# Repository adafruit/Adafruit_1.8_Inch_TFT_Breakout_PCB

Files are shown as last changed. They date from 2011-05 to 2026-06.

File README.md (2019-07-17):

# 1.8" Color TFT LCD display with MicroSD Card Breakout

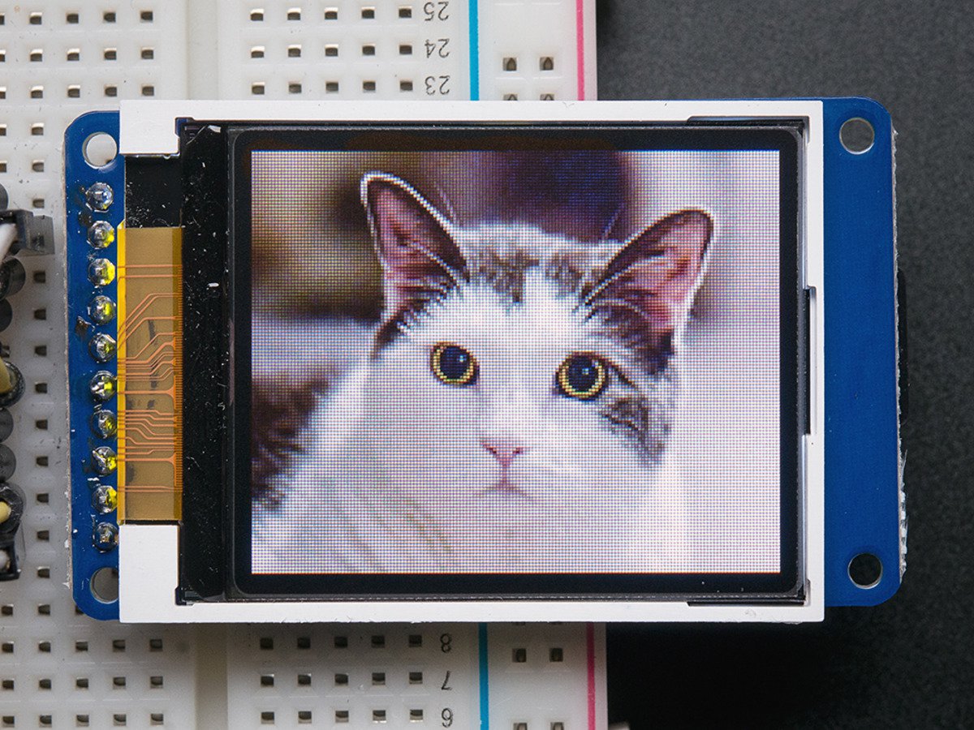
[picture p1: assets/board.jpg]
<a href="http://www.adafruit.com/products/358"><br/>Click here to purchase one from the Adafruit shop</a>

This lovely little display breakout is the best way to add a small, colorful and bright display to any project. Since the display uses 4-wire SPI to communicate and has its own pixel-addressable frame buffer, it can be used with every kind of microcontroller. Even a very small one with low memory and few pins available!

The 1.8" display has 128x160 color pixels. Unlike the low cost "Nokia 6110" and similar LCD displays, which are CSTN type and thus have poor color and slow refresh, this display is a true TFT! The TFT driver (ST7735R) can display full 18-bit color (262,144 shades!). And the LCD will always come with the same driver chip so there's no worries that your code will not work from one to the other.

The breakout has the TFT display soldered on (it uses a delicate flex-circuit connector) as well as a ultra-low-dropout 3.3V regulator and a 3/5V level shifter so you can use it with 3.3V or 5V power and logic. We also had a little space so we placed a microSD card holder so you can easily load full color bitmaps from a FAT16/FAT32 formatted microSD card. The microSD card is not included, [but you can pick one up here](https://www.adafruit.com/product/102).

Of course, we wouldn't just leave you with a datasheet and a "good luck!" - [we've written a full open source graphics library that can draw pixels, lines, rectangles, circles, text and bitmaps as well as example code and a wiring tutorial](https://learn.adafruit.com/1-8-tft-display). The code is written for Arduino but can be easily ported to your favorite microcontroller!

### License

Adafruit invests time and resources providing this open source design, please support Adafruit and open-source hardware by purchasing products from [Adafruit](https://www.adafruit.com)!

Designed by Limor Fried/Ladyada for Adafruit Industries.

Creative Commons Attribution/Share-Alike, all text above must be included in any redistribution. See license.txt for additional details.

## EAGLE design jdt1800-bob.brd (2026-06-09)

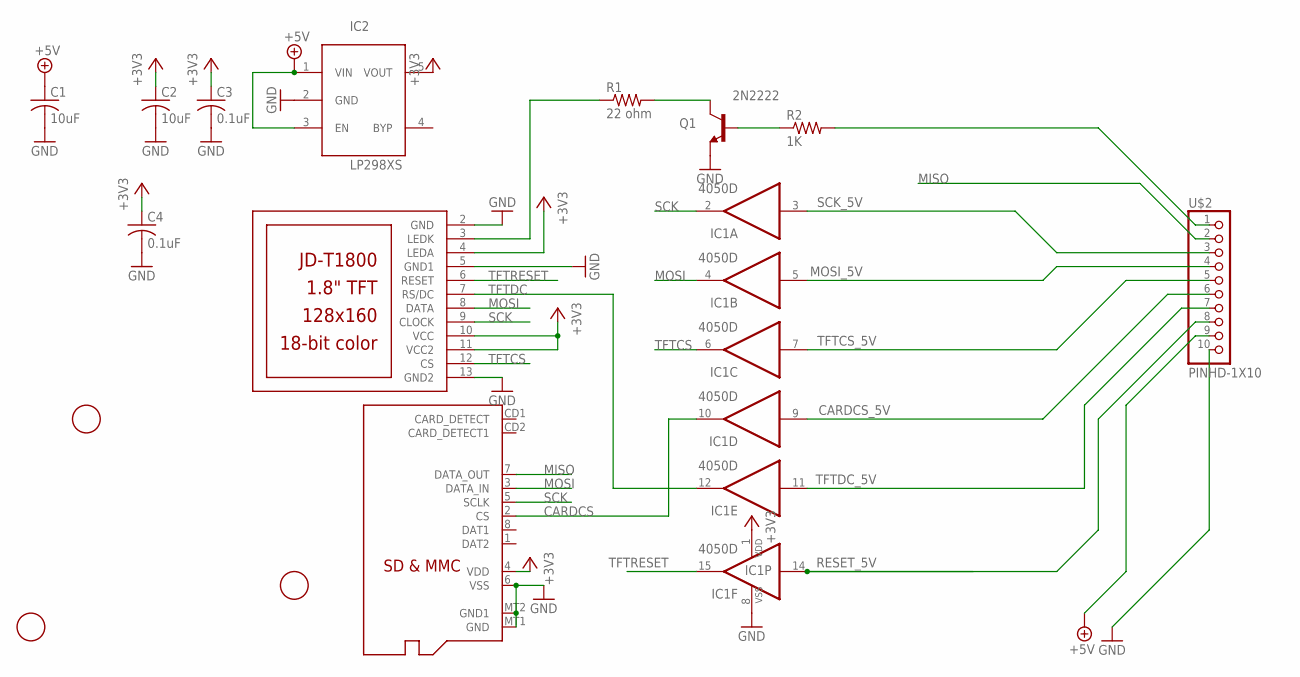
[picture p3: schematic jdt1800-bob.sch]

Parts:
C1, C2: 10uF; C0805K
C3, C4: 0.1uF; C0805K
IC1: 4050D; SO16
IC2: LP298XS; SOT23-5L
Q1: 2N2222; SOT23-BEC
Q2: MICROSD
R1: 22 ohm; R0805
R2: 1K; R0805
U$1: JD-T1800
U$2: PINHD-1X10; 1X10-BIG
U$3, U$4, U$5: FIDUCIAL; FIDUCIAL_1MM

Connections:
+3V3: C2.1, C3.1, C4.1, IC1.1 (VDD), IC2.5 (VOUT), Q2.4 (VDD), U$1.4 (LEDA), U$1.10 (VCC), U$1.11 (VCC2)
+5V: C1.1, IC2.1 (VIN), IC2.3 (EN), U$2.9
CARDCS: IC1.10 (O), Q2.2 (CS)
CARDCS_5V: IC1.9 (I), U$2.6
GND: C1.2, C2.2, C3.2, C4.2, IC1.8 (VSS), IC2.2 (GND), Q1.E, Q2.6 (VSS), Q2.MT1 (GND), Q2.MT2 (GND1), U$1.2 (GND), U$1.5 (GND1), U$1.13 (GND2), U$2.10
MISO: Q2.7 (DATA_OUT), U$2.2
MOSI: IC1.4 (O), Q2.3 (DATA_IN), U$1.8 (DATA)
MOSI_5V: IC1.5 (I), U$2.4
unnamed: Q1.B, R2.1
unnamed: R1.1, U$1.3 (LEDK)
unnamed: Q1.C, R1.2
unnamed: R2.2, U$2.1
RESET_5V: IC1.14 (I), U$2.8
SCK: IC1.2 (O), Q2.5 (SCLK), U$1.9 (CLOCK)
SCK_5V: IC1.3 (I), U$2.3
TFTCS: IC1.6 (O), U$1.12 (CS)
TFTCS_5V: IC1.7 (I), U$2.5
TFTDC: IC1.12 (O), U$1.7 (RS/DC)
TFTDC_5V: IC1.11 (I), U$2.7
TFTRESET: IC1.15 (O), U$1.6 (RESET)

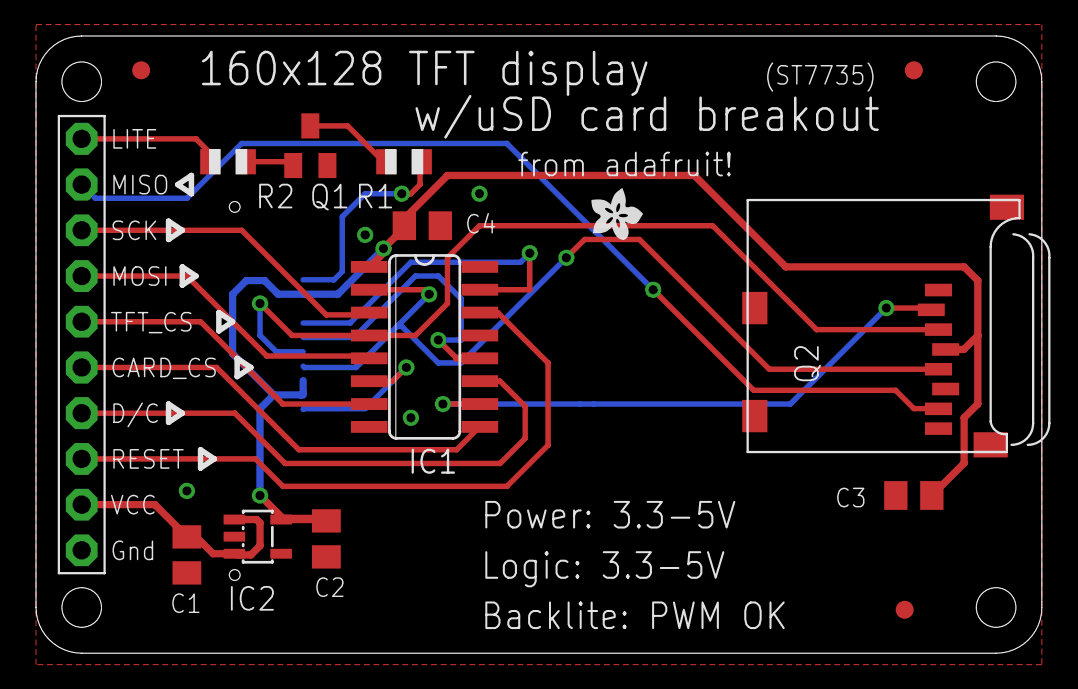
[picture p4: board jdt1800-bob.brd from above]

Board: 2 copper layers, 55.9 x 34.3 mm, 16 parts (1 on the bottom side), 20 nets.

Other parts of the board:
U$6: ADAFRUIT200MIL

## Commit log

2011-05-30 eaglecad files
    [jdt1800-bob.brd, jdt1800-bob.sch]
2026-06-03 update file format to XML
    [jdt1800-bob.brd, jdt1800-bob.sch]
